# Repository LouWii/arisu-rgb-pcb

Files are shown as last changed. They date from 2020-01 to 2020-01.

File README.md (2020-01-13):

# Arisu Keyboard PCB - RGB & DIY mod

Arisu RGB Keyboard PCB, originally designed by [FateNozomi](https://github.com/FateNozomi), modified by [LouWii](https://github.com/LouWii).

The main differences with the original design are:

* RGB LEDs added for underglow (12 LEDs)
* Some components replaced with their through-hole version for easy soldering
* Micro-USB replaced with a mini-USB with through-hole soldering (for better strength)

The layout remains **unchanged** from the original design.

Original presentation:

> アリス PCB designed using KiCad. The layout is inspired by Lyn's EM7 and TGR Alice with some modification of my own.
>
> Key differences:
>
> * I removed the extra [B] key on the right half and shifted the [NM,.?] row to the left by 0.25U.
> * Shifted the 3 keys to the right and added arrow keys.
> * Tweaked the bottom so that the 1.5U keys doesn't protrude out a little.

> Shifting the [NM,.?] row to the left by 0.25U required quite some work on the arrangement of keys for the right half.
> As a result, this does not give the same typing experience as Lyn's EM7 and TGR Alice.
> Lyn's EM7 and TGR Alice uses the home row as the center point to vertically align both halves while I used the number row instead.
> Due to the nature of staggered keyboards, aligning using the number row resulted in the home row not being aligned.

Disclaimer: Use these files at your own risk.

Arisu
Arisu-top
アリス

## Gerber Files
Download the gerber files under [releases](https://github.com/FateNozomi/arisu-pcb/releases).

## Assembly
For the components required, you may refer to the bill of materials included along with the release as reference or load up the design file in KiCad.
All the components can be soldered using a regular soldering iron, though soldering the Micro USB receptacle might be the biggest hurdle.

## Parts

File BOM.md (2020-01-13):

# BOM

The mini-USB used is from Omron: XM7D-0512. Footprint and 3d model on [SnapEDA](https://www.snapeda.com/parts/XM7D-0512/Omron%20Electronics/view-part/?ref=search&amp;t=XM7D-0512).

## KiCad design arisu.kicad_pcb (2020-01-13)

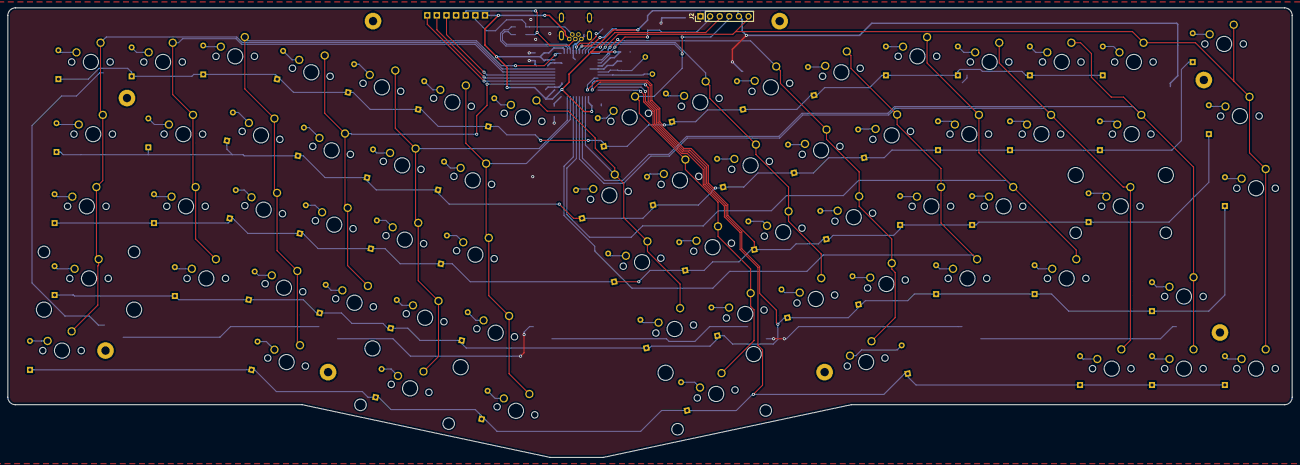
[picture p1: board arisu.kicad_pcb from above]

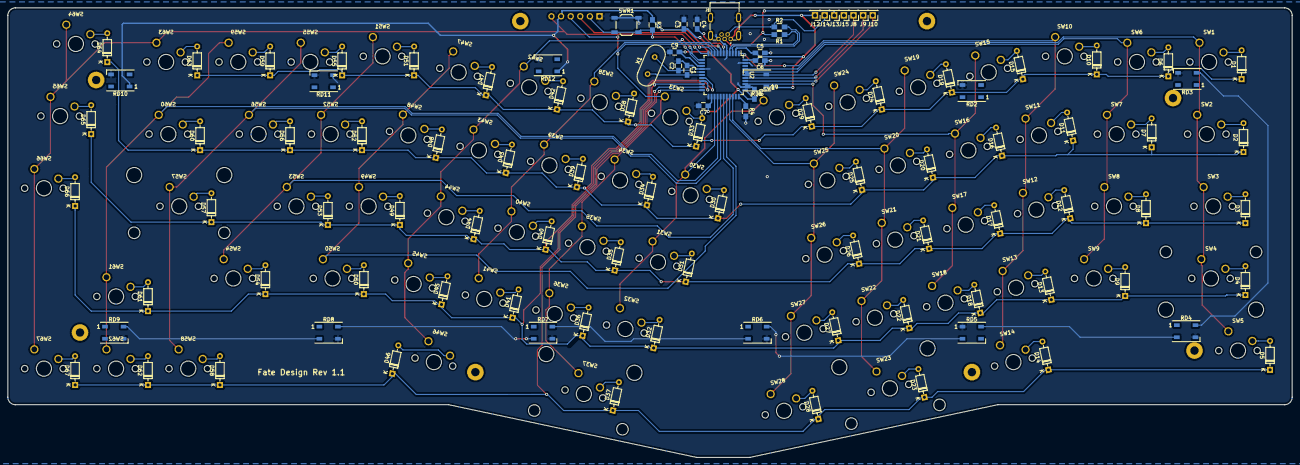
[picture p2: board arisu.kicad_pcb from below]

Board: 2 copper layers, 339.1 x 118.7 mm, 179 parts (103 on the bottom side), 114 nets.

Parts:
C1, C2: 22pF; C_0805_HandSoldering
C3: 10uF; C_0805_HandSoldering
C4: 1uF (±10%); C_0805_HandSoldering
C5: 1uF; C_0805_HandSoldering
C6, C7, C8, C9: 0.1uF; C_0805_HandSoldering
D1, D2, D3, D4, D5, D6, D7, D8, D9, D10, D11, D12, D13, D14, D15, D16, D17, D18, D19, D20, D21, D22, D23, D24, D25, D26, D27, D28, D29, D30, D31, D32, D33, D34, D35, D36, D37, D38, D39, D40, D41, D42, D43, D44, D45, D46, D47, D48, D49, D50, D51, D52, D53, D54, D55, D56, D57, D58, D59, D60, D61, D62, D63, D64, D65, D66, D67: D; D_DO-35_SOD27_P7.62mm_Horizontal
H1, H2, H3, H4, H5, H6, H7, H8: MountingHole; MountingHole_2.2mm_M2_Pad
J1: USB_B_Mini; Mini-USB-B_OMRON_XM7D-0512
J2: 1x6 2.54mm; PinHeader_1x06_P2.54mm_Vertical
J8: PF4; PinHeader_1x01_P2.54mm_Vertical
J9: PF5; PinHeader_1x01_P2.54mm_Vertical
J10: PF6; PinHeader_1x01_P2.54mm_Vertical
J12: VCC; PinHeader_1x01_P2.54mm_Vertical
J13: D+; PinHeader_1x01_P2.54mm_Vertical
J14: D-; PinHeader_1x01_P2.54mm_Vertical
J15: GND; PinHeader_1x01_P2.54mm_Vertical
R1, R2: 22; R_0805_HandSoldering
R3, R4: 10K; R_0805_HandSoldering
RD1, RD2, RD3, RD4, RD5, RD6, RD7, RD8, RD9, RD10, RD11, RD12: WS2812B; LED_WS2812B_PLCC4_5.0x5.0mm_P3.2mm
SW1, SW6, SW7, SW8, SW9, SW10, SW11, SW12, SW13, SW15, SW16, SW17, SW18, SW19, SW20, SW21, SW22, SW24, SW25, SW26, SW27, SW28, SW29, SW30, SW31, SW32, SW33, SW34, SW35, SW36, SW38, SW39, SW40, SW41, SW42, SW43, SW44, SW45, SW47, SW48, SW49, SW50, SW51, SW52, SW53, SW55, SW56, SW58, SW59, SW61, SW62, SW63, SW64, SW65, SW66, SW67: SW_Push; SW_Cherry_MX_1.00u_PCB
SW2, SW5, SW14, SW46, SW60: SW_Push; SW_Cherry_MX_1.50u_PCB
SW3, SW54: SW_Push; SW_Cherry_MX_1.75u_PCB
SW4: SW_Push; SW_Cherry_MX_2.25u_PCB
SW23: SW_Push; SW_Cherry_MX_2.00u_PCB_ReversedStabilizers
SW37: SW_Push; SW_Cherry_MX_2.75u_PCB_ReversedStabilizers
SW57: SW_Push; SW_Cherry_MX_2.25u_PCB_ReversedStabilizers
SWR1: SW_Push; SW_SPST_TL3342
U2: ATmega32U4-AU; TQFP-44_10x10mm_P0.8mm
X1: 16Mhz; Crystal_HC49-U_Vertical

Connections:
/MISO: J2.6, SW63.1, SW64.1, SW65.1, SW66.1, SW67.1, U2.11
/MOSI: J2.3, U2.10
/PF4: J8.1, U2.39
/PF5: J9.1, U2.38
/PF6: J10.1, U2.37
/SCK: J2.4, SW33.1, SW34.1, SW35.1, SW36.1, SW37.1, U2.9
/col0: SW1.1, SW2.1, SW3.1, SW4.1, SW5.1, U2.41
/col1: SW6.1, SW7.1, SW8.1, SW9.1, U2.40
/col2: SW10.1, SW11.1, SW12.1, SW13.1, SW14.1, U2.1
/col3: SW15.1, SW16.1, SW17.1, SW18.1, U2.36
/col4: SW19.1, SW20.1, SW21.1, SW22.1, SW23.1, U2.31
/col5: SW24.1, SW25.1, SW26.1, SW27.1, SW28.1, U2.30
/col6: SW29.1, SW30.1, SW31.1, SW32.1, U2.25
/col8: SW38.1, SW39.1, SW40.1, SW41.1, U2.8
/col9: SW42.1, SW43.1, SW44.1, SW45.1, SW46.1, U2.12
/col10: SW47.1, SW48.1, SW49.1, SW50.1, U2.29
/col11: SW51.1, SW52.1, SW53.1, SW54.1, U2.28
/col12: SW55.1, SW56.1, SW57.1, SW58.1, U2.27
/col13: SW59.1, SW60.1, SW61.1, SW62.1, U2.26
/row0: D1.1, D6.1, D10.1, D15.1, D19.1, D24.1, D29.1, D33.1, D38.1, D42.1, D47.1, D51.1, D55.1, D59.1, D63.1, U2.18
/row1: D2.1, D7.1, D11.1, D16.1, D20.1, D25.1, D30.1, D34.1, D39.1, D43.1, D48.1, D52.1, D56.1, D60.1, D64.1, U2.19
/row2: D3.1, D8.1, D12.1, D17.1, D21.1, D26.1, D31.1, D35.1, D40.1, D44.1, D49.1, D53.1, D57.1, D65.1, U2.20
/row3: D4.1, D9.1, D13.1, D18.1, D22.1, D27.1, D32.1, D36.1, D41.1, D45.1, D50.1, D54.1, D61.1, D66.1, U2.21
/row4: D5.1, D14.1, D23.1, D28.1, D37.1, D46.1, D58.1, D62.1, D67.1, U2.22
/~RES~: J2.2, R3.2, SWR1.2, U2.13
D+: R1.1, U2.4
D-: R2.1, U2.3
GND: C1.1, C2.2, C3.2, C4.2, C5.2, C6.2, C7.2, C8.2, C9.2, J1.5, J1.6, J2.1, J15.1, R4.2, RD1.3, RD2.3, RD3.3, RD4.3, RD5.3, RD6.3, RD7.3, RD8.3, RD9.3, RD10.3, RD11.3, RD12.3, SWR1.1, U2.5, U2.15, U2.23, U2.35, U2.43
unnamed: C4.1, U2.6
unnamed: D1.2, SW1.2
unnamed: D2.2, SW2.2
unnamed: D3.2, SW3.2
unnamed: D4.2, SW4.2
unnamed: D5.2, SW5.2
unnamed: D6.2, SW6.2
unnamed: D7.2, SW7.2
unnamed: D8.2, SW8.2
unnamed: D9.2, SW9.2
unnamed: D10.2, SW10.2
unnamed: D11.2, SW11.2
unnamed: D12.2, SW12.2
unnamed: D13.2, SW13.2
unnamed: D14.2, SW14.2
unnamed: D15.2, SW15.2
unnamed: D16.2, SW16.2
unnamed: D17.2, SW17.2
unnamed: D18.2, SW18.2
unnamed: D19.2, SW19.2
unnamed: D20.2, SW20.2
unnamed: D21.2, SW21.2
unnamed: D22.2, SW22.2
unnamed: D23.2, SW23.2
unnamed: D24.2, SW24.2
unnamed: D25.2, SW25.2
unnamed: D26.2, SW26.2
unnamed: D27.2, SW27.2
unnamed: D28.2, SW28.2
unnamed: D29.2, SW29.2
unnamed: D30.2, SW30.2
unnamed: D31.2, SW31.2
unnamed: D32.2, SW32.2
unnamed: D33.2, SW33.2
unnamed: D34.2, SW34.2
unnamed: D35.2, SW35.2
unnamed: D36.2, SW36.2
unnamed: D37.2, SW37.2
unnamed: D38.2, SW38.2
unnamed: D39.2, SW39.2
unnamed: D40.2, SW40.2
unnamed: D41.2, SW41.2
unnamed: D42.2, SW42.2
unnamed: D43.2, SW43.2
unnamed: D44.2, SW44.2
unnamed: D45.2, SW45.2
unnamed: D46.2, SW46.2
unnamed: D47.2, SW47.2
unnamed: D48.2, SW48.2
unnamed: D49.2, SW49.2
unnamed: D50.2, SW50.2
unnamed: D51.2, SW51.2
unnamed: D52.2, SW52.2
unnamed: D53.2, SW53.2
unnamed: D54.2, SW54.2
unnamed: D55.2, SW55.2
unnamed: D56.2, SW56.2
unnamed: D57.2, SW57.2
unnamed: D58.2, SW58.2
unnamed: D59.2, SW59.2
unnamed: D60.2, SW60.2
unnamed: D61.2, SW61.2
unnamed: D62.2, SW62.2
unnamed: D63.2, SW63.2
unnamed: D64.2, SW64.2
unnamed: D65.2, SW65.2
unnamed: D66.2, SW66.2
unnamed: D67.2, SW67.2
unnamed: J1.2, J14.1, R2.2
unnamed: J1.3, J13.1, R1.2
unnamed: R4.1, U2.33
unnamed: RD1.2, RD2.4
unnamed: RD2.2, RD3.4
unnamed: RD3.2, RD4.4
unnamed: RD4.2, RD5.4
unnamed: RD5.2, RD6.4
unnamed: RD6.2, RD7.4
unnamed: RD7.2, RD8.4
unnamed: RD8.2, RD9.4
unnamed: RD10.2, RD11.4
unnamed: RD9.2, RD10.4
unnamed: RD11.2, RD12.4
RGBIN: RD1.4, U2.32
VCC: C3.1, C5.1, C6.1, C7.1, C8.1, C9.1, J1.1, J2.5, J12.1, R3.1, RD1.1, RD2.1, RD3.1, RD4.1, RD5.1, RD6.1, RD7.1, RD8.1, RD9.1, RD10.1, RD11.1, RD12.1, U2.2, U2.7, U2.14, U2.24, U2.34, U2.44
XTAL1: C1.2, U2.17, X1.1
XTAL2: C2.1, U2.16, X1.2

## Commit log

2020-01-13 Replace components, place RGB leds, update traces - WIP
    [arisu.kicad_pcb]
2020-01-13 add WIP BOM list, add 3d model for USB port
    [arisu.kicad_pcb]
